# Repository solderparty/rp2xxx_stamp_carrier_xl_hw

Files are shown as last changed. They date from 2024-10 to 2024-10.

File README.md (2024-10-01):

# The RP2xxx Stamp Carrier Board XL

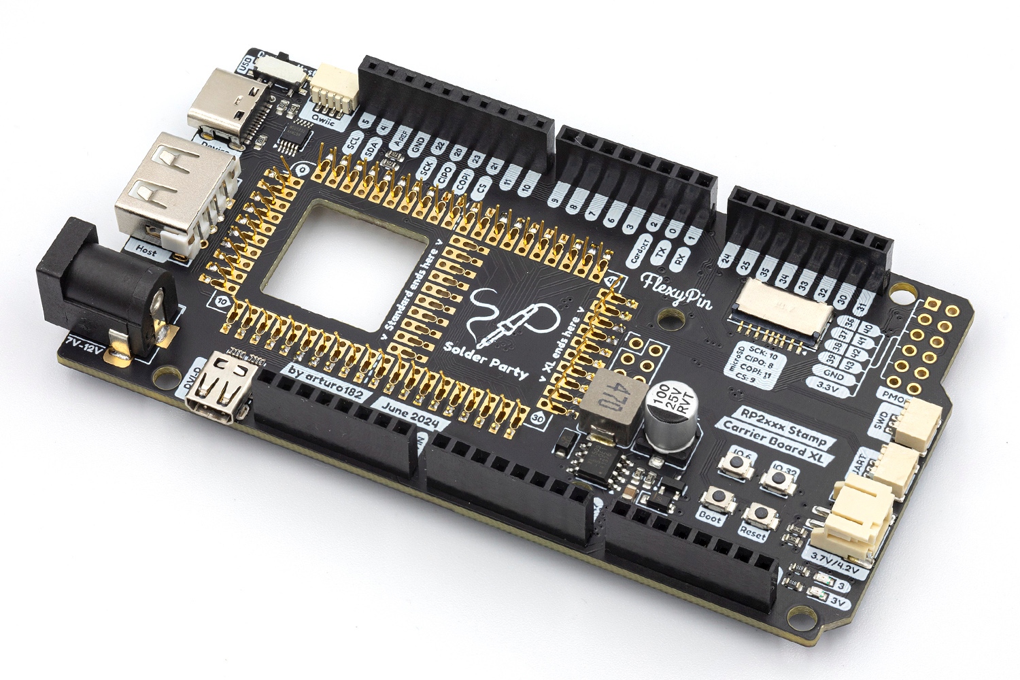
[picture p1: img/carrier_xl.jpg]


The RP2xxx Stamp Carrier XL, as the (somewhat long) name suggests, supports all the RP2-based Stamp boards. The Mega/Due form-factor ensures compatbility with many shields, including Uno ones. The wide range of connectors on the Carrier makes it a fully-fledged RP2xxx dev board.

The Carrier comes with a combo 3-in-1 SMD/TH/FlexyPin Stamp footprint, you can solder the Stamp directly to the Carrier, use 2mm pin headers + sockets to be able to plug it in and out, or use [FlexyPins](https://docs.solder.party/flexypin) to pop the Stamp in and out of the Carrier would soldering the Stamp. This way the Carrier also acts as a great Stamp flashing and testing jig. Check out the [Assembly Options](https://docs.solder.party/rp2xxx-stamp-carrier-xl/assembly_options) page for more details.

The board can be powered from the LiPo, over USB, or with a DC jack.

By using the RP2040 Stamp Carrier, you get everything that comes with the Stamp plus:

- USB Host and Device connectors with a toggle switch
- microSD socket
- Micro HDMI-shaped connector, connected to the HSTX peripheral
- SWD JST connector, compatible with the Raspberry Pi Pico Probe
- UART JST connector, compatible with the Raspberry Pi Pico Probe
- Qwiic connector
- 3.7/4.2V LiPo connector
- two user buttons
- PMOD header
- USR LED
- Power (3.3V) LED
- DC Jack

The DC Jack input is center-positive and supports voltages in the range of 7-12V. If you have the LiPo and either DC or USB connected, the battery will begin charging.

As mentioned above, the Carrier follows the Mega/Due/Uno shield pinout, making it compatible with a large ecosystem of shields, as long as they work on 3.3V IOs. **The pins are not 5V-tolerant**.

The CircuitPython firmware for the Stamps comes with a built-in board file for the Carrier, you can access it using `import stamp_carrier_board_xl as board`. After that, you can access all the Carrier pins and interfaces like you would with any other CPY board.

# Links

For more information visit https://rp2xxx-stamp-carrier-xl.solder.party/

Buy it on Lectronz (https://lectronz.com/products/rp2xxx-stamp-carrier-xl)

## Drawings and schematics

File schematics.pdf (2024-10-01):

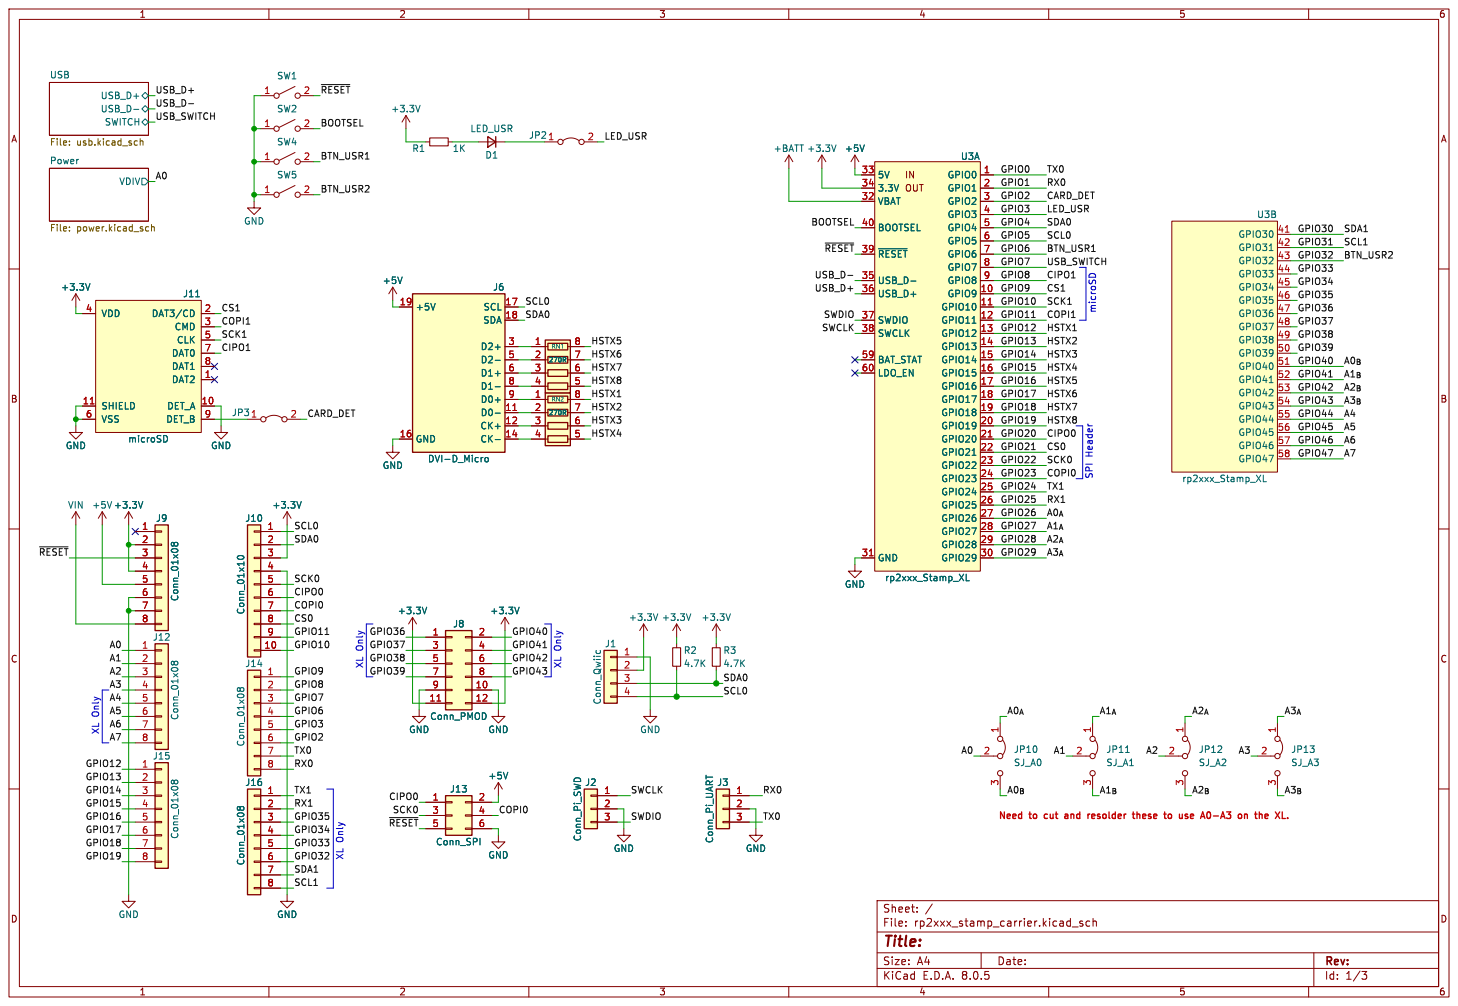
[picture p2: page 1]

Power File: power.kicad_sch USB_D+ USB_D- SWITCH

Id: 1/3 Title: File: rp2xxx_stamp_carrier.kicad_sch Sheet: /

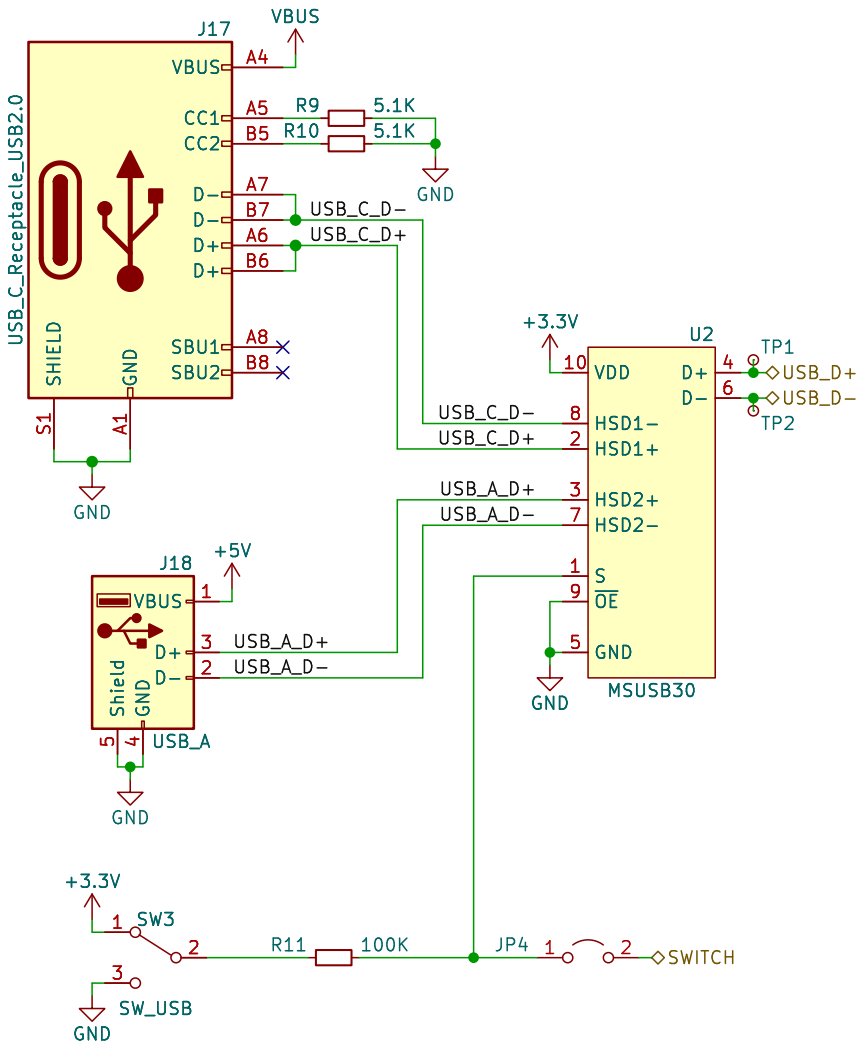
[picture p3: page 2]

Id: 2/3 Title: File: usb.kicad_sch Sheet: /USB/

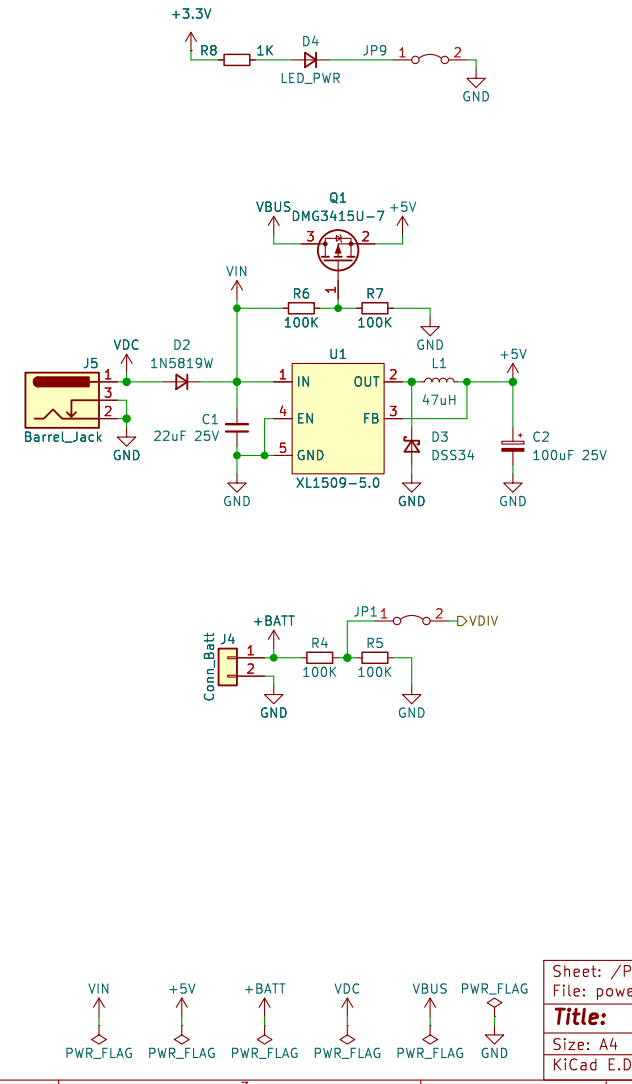
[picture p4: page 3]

Id: 3/3 Title: File: power.kicad_sch Sheet: /Power/ PWR_FLAG

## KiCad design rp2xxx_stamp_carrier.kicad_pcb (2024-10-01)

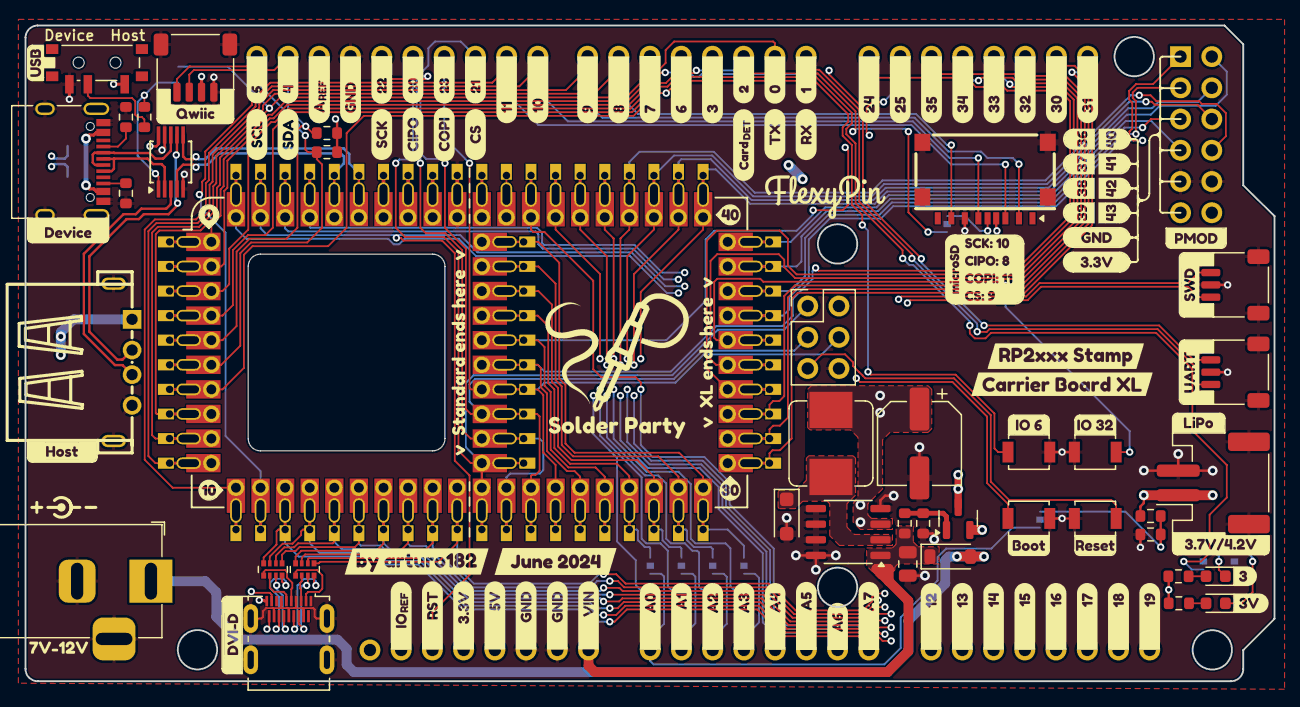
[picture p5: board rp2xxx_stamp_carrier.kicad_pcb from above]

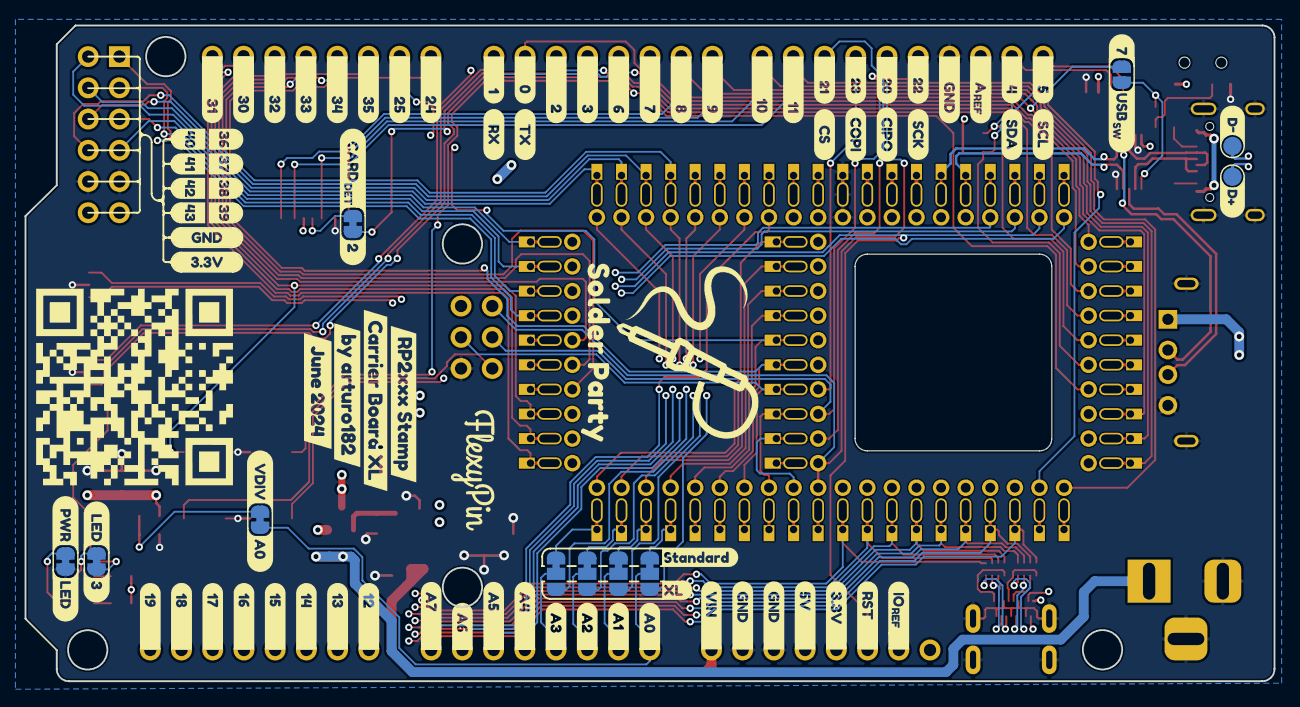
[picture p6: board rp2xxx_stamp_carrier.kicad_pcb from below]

Board: 4 copper layers, 101.6 x 53.3 mm, 255 parts (105 on the bottom side), 89 nets.

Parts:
C1: 22uF 25V; C_0805_2012Metric
C2: 100uF 25V; CP_Elec_6.3x4.9
D1: LED_USR; LED_0603_1608Metric
D2: 1N5819W; D_SOD-123
D3: DSS34; D_SOD-123F
D4: LED_PWR; LED_0603_1608Metric
J1: Conn_Qwiic; JST_SH_SM04B-SRSS-TB_1x04-1MP_P1.00mm_Horizontal
J2: Conn_Pi_SWD; JST_SH_SM03B-SRSS-TB_1x03-1MP_P1.00mm_Horizontal
J3: Conn_Pi_UART; JST_SH_SM03B-SRSS-TB_1x03-1MP_P1.00mm_Horizontal
J4: Conn_Batt; JST_PH_S2B-PH-SM4-TB_1x02-1MP_P2.00mm_Horizontal
J5: Barrel_Jack; BarrelJack_Horizontal
J6: DVI-D_Micro; HDMI_Micro-D_Molex_46765-1x01
J8: Conn_PMOD; PinSocket_2x06_P2.54mm_Vertical
J9, J12, J14, J15, J16: Conn_01x08; PinSocket_1x08_P2.54mm_Vertical
J10: Conn_01x10; PinSocket_1x10_P2.54mm_Vertical
J11: microSD; XUNPU_TF-123-ARP9Hxx
J13: Conn_SPI; PinHeader_2x03_P2.54mm_Vertical
J17: USB_C_Receptacle_USB2.0; USB_C_Receptacle_XKB_U262-16XN-4BVC11
J18: USB_A; USB_A_Receptacle_908-261A1011D10100
JP1: JP_VDIV; SolderJumper-2_P1.3mm_Bridged_RoundedPad1.0x1.5mm
JP2: JP_LED_USR; SolderJumper-2_P1.3mm_Bridged_RoundedPad1.0x1.5mm
JP3: JP_SD_DET; SolderJumper-2_P1.3mm_Bridged_RoundedPad1.0x1.5mm
JP4: JP_USB_SWITCH; SolderJumper-2_P1.3mm_Open_RoundedPad1.0x1.5mm
JP9: JP_LED_PWR; SolderJumper-2_P1.3mm_Bridged_RoundedPad1.0x1.5mm
JP10: SJ_A0; SolderJumper-3_P1.3mm_Bridged12_RoundedPad1.0x1.5mm
JP11: SJ_A1; SolderJumper-3_P1.3mm_Bridged12_RoundedPad1.0x1.5mm
JP12: SJ_A2; SolderJumper-3_P1.3mm_Bridged12_RoundedPad1.0x1.5mm
JP13: SJ_A3; SolderJumper-3_P1.3mm_Bridged12_RoundedPad1.0x1.5mm
L1: 47uH; L_Bourns_SRP7028A_7.3x6.6mm
Q1: DMG3415U-7; SOT-23
R1, R8: 1K; R_0603_1608Metric
R2, R3: 4.7K; R_0603_1608Metric
R4, R5, R6, R7, R11: 100K; R_0603_1608Metric
R9, R10: 5.1K; R_0603_1608Metric
RN1, RN2: 270R; R_Array_Convex_4x0402
SW1: BTN_RESET; SW_SPST_B3U-1000P
SW2: BTN_BOOTSEL; SW_SPST_B3U-1000P
SW3: SW_USB; SW_SPDT_PCM12
SW4: BTN_USR1; SW_SPST_B3U-1000P
SW5: BTN_USR2; SW_SPST_B3U-1000P
TP1: TP_USB_D+; TestPoint_Pad_D1.5mm
TP2: TP_USB_D-; TestPoint_Pad_D1.5mm
U1: XL1509-5.0; SOP-8_3.9x4.9mm_P1.27mm
U2: MSUSB30; MSOP-10_3x3mm_P0.5mm
U3: rp2xxx_Stamp_XL; RP2xx_Stamp_FlexyPin
kibuzzard-65DA3D92, kibuzzard-65DA3D92#2: G***; kibuzzard-65DA3D92
kibuzzard-65DA3D96, kibuzzard-65DA3D96#2: G***; kibuzzard-65DA3D96
kibuzzard-65DA3DCF: G***; kibuzzard-65DA3DCF
kibuzzard-65DA3ED0: G***; kibuzzard-65DA3ED0
kibuzzard-65DA3EE8, kibuzzard-65DA3EE8#2, kibuzzard-65DA3EE8#3, kibuzzard-65DA3EE8#4: G***; kibuzzard-65DA3EE8
kibuzzard-65DA13F9: G***; kibuzzard-65DA13F9
kibuzzard-65DA35ED: G***; kibuzzard-65DA35ED
kibuzzard-65DA43E4: G***; kibuzzard-65DA43E4
kibuzzard-65DA140C: G***; kibuzzard-65DA140C
kibuzzard-65DA141A: G***; kibuzzard-65DA141A
kibuzzard-65DA141E: G***; kibuzzard-65DA141E
kibuzzard-65DA143D: G***; kibuzzard-65DA143D
kibuzzard-65DA144D: G***; kibuzzard-65DA144D
kibuzzard-65DA145C: G***; kibuzzard-65DA145C
kibuzzard-65DA146D: G***; kibuzzard-65DA146D
kibuzzard-65DA148C: G***; kibuzzard-65DA148C
kibuzzard-65DA150C: G***; kibuzzard-65DA150C
kibuzzard-65DA150E: G***; kibuzzard-65DA150E
kibuzzard-65DA445F, kibuzzard-65DA445F#2: G***; kibuzzard-65DA445F
kibuzzard-65DA451B: G***; kibuzzard-65DA451B
kibuzzard-65DA451F: G***; kibuzzard-65DA451F
kibuzzard-65DA1408: G***; kibuzzard-65DA1408
kibuzzard-65DA1410: G***; kibuzzard-65DA1410
kibuzzard-65DA1413: G***; kibuzzard-65DA1413
kibuzzard-65DA1417: G***; kibuzzard-65DA1417
kibuzzard-65DA1440: G***; kibuzzard-65DA1440
kibuzzard-65DA1442: G***; kibuzzard-65DA1442
kibuzzard-65DA1448: G***; kibuzzard-65DA1448
kibuzzard-65DA1450: G***; kibuzzard-65DA1450
kibuzzard-65DA1453: G***; kibuzzard-65DA1453
kibuzzard-65DA1457: G***; kibuzzard-65DA1457
kibuzzard-65DA1460: G***; kibuzzard-65DA1460
kibuzzard-65DA1463: G***; kibuzzard-65DA1463
kibuzzard-65DA1466: G***; kibuzzard-65DA1466
kibuzzard-65DA1469: G***; kibuzzard-65DA1469
kibuzzard-65DA1470: G***; kibuzzard-65DA1470
kibuzzard-65DA1473: G***; kibuzzard-65DA1473
kibuzzard-65DA1483: G***; kibuzzard-65DA1483
kibuzzard-65DA1486: G***; kibuzzard-65DA1486
kibuzzard-65DA1492: G***; kibuzzard-65DA1492
kibuzzard-65DA1508: G***; kibuzzard-65DA1508
kibuzzard-65DA1511: G***; kibuzzard-65DA1511
kibuzzard-65DA1514: G***; kibuzzard-65DA1514
kibuzzard-65DA1517: G***; kibuzzard-65DA1517
kibuzzard-65DA4352: G***; kibuzzard-65DA4352
kibuzzard-65DA4391, kibuzzard-65DA4391#2, kibuzzard-65DA4391#3, kibuzzard-65DA4391#4: G***; kibuzzard-65DA4391
kibuzzard-65DA4455, kibuzzard-65DA4455#2: G***; kibuzzard-65DA4455
kibuzzard-65DA4463, kibuzzard-65DA4463#2: G***; kibuzzard-65DA4463
kibuzzard-65DA4468, kibuzzard-65DA4468#2: G***; kibuzzard-65DA4468
kibuzzard-65DA4513, kibuzzard-65DA4513#2: G***; kibuzzard-65DA4513
kibuzzard-65DA4517, kibuzzard-65DA4517#2: G***; kibuzzard-65DA4517
kibuzzard-65DB6F6F: G***; kibuzzard-65DB6F6F
kibuzzard-65DB8C3D: G***; kibuzzard-65DB8C3D
kibuzzard-65DB8C4A: G***; kibuzzard-65DB8C4A
kibuzzard-65DB8C5D: G***; kibuzzard-65DB8C5D
kibuzzard-65DB8C6C: G***; kibuzzard-65DB8C6C
kibuzzard-65DB8C35: G***; kibuzzard-65DB8C35
kibuzzard-65DB8C43: G***; kibuzzard-65DB8C43
kibuzzard-65DB8C55: G***; kibuzzard-65DB8C55
kibuzzard-65DB8C65: G***; kibuzzard-65DB8C65
kibuzzard-65DB8CB7: G***; kibuzzard-65DB8CB7
kibuzzard-65DB8EB0: G***; kibuzzard-65DB8EB0
kibuzzard-65DB9A5B: G***; kibuzzard-65DB9A5B
kibuzzard-65DB9AC9: G***; kibuzzard-65DB9AC9
kibuzzard-65DB9ADE: G***; kibuzzard-65DB9ADE
kibuzzard-65DB9BDD: G***; kibuzzard-65DB9BDD
kibuzzard-65DB9C6E: G***; kibuzzard-65DB9C6E
kibuzzard-65DB9FCE: G***; kibuzzard-65DB9FCE
kibuzzard-65DB9FED: G***; kibuzzard-65DB9FED
kibuzzard-65DB88A1: G***; kibuzzard-65DB88A1
kibuzzard-65DB90A8: G***; kibuzzard-65DB90A8
kibuzzard-65DB90AF: G***; kibuzzard-65DB90AF
kibuzzard-65DB90B6: G***; kibuzzard-65DB90B6
kibuzzard-65DB90CA: G***; kibuzzard-65DB90CA
kibuzzard-65DB92A0: G***; kibuzzard-65DB92A0
kibuzzard-65DB92A7: G***; kibuzzard-65DB92A7
kibuzzard-65DB92AF: G***; kibuzzard-65DB92AF
kibuzzard-65DB92BE: G***; kibuzzard-65DB92BE
kibuzzard-65DB92C6: G***; kibuzzard-65DB92C6
kibuzzard-65DB92CE: G***; kibuzzard-65DB92CE
kibuzzard-65DB92F8: G***; kibuzzard-65DB92F8
kibuzzard-65DB97A1: G***; kibuzzard-65DB97A1
kibuzzard-65DB97F6: G***; kibuzzard-65DB97F6
kibuzzard-65DB876F: G***; kibuzzard-65DB876F
kibuzzard-65DB884E: G***; kibuzzard-65DB884E
kibuzzard-65DB908D: G***; kibuzzard-65DB908D
kibuzzard-65DB909F: G***; kibuzzard-65DB909F
kibuzzard-65DB928A: G***; kibuzzard-65DB928A
kibuzzard-65DB931B: G***; kibuzzard-65DB931B
kibuzzard-65DB932B: G***; kibuzzard-65DB932B
kibuzzard-65DB8732: G***; kibuzzard-65DB8732
kibuzzard-65DB8845: G***; kibuzzard-65DB8845
kibuzzard-65DB8856: G***; kibuzzard-65DB8856
kibuzzard-65DB8860: G***; kibuzzard-65DB8860
kibuzzard-65DB9086: G***; kibuzzard-65DB9086
kibuzzard-65DB9096: G***; kibuzzard-65DB9096
kibuzzard-65DB9291: G***; kibuzzard-65DB9291
kibuzzard-65DB9299: G***; kibuzzard-65DB9299
kibuzzard-65DB9324: G***; kibuzzard-65DB9324
kibuzzard-65DBA05E: G***; kibuzzard-65DBA05E
kibuzzard-65DBA5ED: G***; kibuzzard-65DBA5ED
kibuzzard-65DBA047: G***; kibuzzard-65DBA047
kibuzzard-65DBA204: G***; kibuzzard-65DBA204
kibuzzard-65DBAB3B: G***; kibuzzard-65DBAB3B
kibuzzard-65DBAB4B: G***; kibuzzard-65DBAB4B
kibuzzard-65DBAB8B: G***; kibuzzard-65DBAB8B
kibuzzard-65DBAE3B: G***; kibuzzard-65DBAE3B
kibuzzard-65DBAE3E: G***; kibuzzard-65DBAE3E
kibuzzard-65DBAE42: G***; kibuzzard-65DBAE42
kibuzzard-65DBAE46: G***; kibuzzard-65DBAE46
kibuzzard-65DBAFC4: G***; kibuzzard-65DBAFC4
kibuzzard-65DBB0B8: G***; kibuzzard-65DBB0B8
kibuzzard-65DBB1B5: G***; kibuzzard-65DBB1B5
kibuzzard-65DBB3A0: G***; kibuzzard-65DBB3A0
kibuzzard-65DBB5CC: G***; kibuzzard-65DBB5CC
kibuzzard-65DBB07F: G***; kibuzzard-65DBB07F
kibuzzard-65DBB7FE: G***; kibuzzard-65DBB7FE
kibuzzard-65DBB28B: G***; kibuzzard-65DBB28B
kibuzzard-65DBB461: G***; kibuzzard-65DBB461
kibuzzard-65DBB727: G***; kibuzzard-65DBB727
kibuzzard-65DBBE17, kibuzzard-65DBBE17#2: G***; kibuzzard-65DBBE17
kibuzzard-65DBBE25, kibuzzard-65DBBE25#2: G***; kibuzzard-65DBBE25
kibuzzard-65DBBE65, kibuzzard-65DBBE65#2: G***; kibuzzard-65DBBE65
kibuzzard-65DBC04C: G***; kibuzzard-65DBC04C
kibuzzard-65DBC042: G***; kibuzzard-65DBC042
kibuzzard-65DBC046: G***; kibuzzard-65DBC046
kibuzzard-65DBC049: G***; kibuzzard-65DBC049
kibuzzard-65DBC50C: G***; kibuzzard-65DBC50C
kibuzzard-65DBC86E: G***; kibuzzard-65DBC86E
kibuzzard-65DBC416: G***; kibuzzard-65DBC416
kibuzzard-65DBC874: G***; kibuzzard-65DBC874
kibuzzard-65DBD3AD: G***; kibuzzard-65DBD3AD
kibuzzard-65DBD7D2, kibuzzard-65DBD7D2#2: G***; kibuzzard-65DBD7D2
kibuzzard-65DBD8C5, kibuzzard-65DBD8C5#2: G***; kibuzzard-65DBD8C5
kibuzzard-65DBD8CA, kibuzzard-65DBD8CA#2: G***; kibuzzard-65DBD8CA
kibuzzard-65DBD83D, kibuzzard-65DBD83D#2: G***; kibuzzard-65DBD83D
kibuzzard-65DBD87F, kibuzzard-65DBD87F#2: G***; kibuzzard-65DBD87F
kibuzzard-65DBD479: G***; kibuzzard-65DBD479
kibuzzard-65DBD837, kibuzzard-65DBD837#2: G***; kibuzzard-65DBD837
kibuzzard-65DBD847, kibuzzard-65DBD847#2: G***; kibuzzard-65DBD847
kibuzzard-65DBD875, kibuzzard-65DBD875#2: G***; kibuzzard-65DBD875
kibuzzard-65DBDBD8: G***; kibuzzard-65DBDBD8
kibuzzard-65DBDBE3: G***; kibuzzard-65DBDBE3
kibuzzard-65DBDBF9: G***; kibuzzard-65DBDBF9
kibuzzard-65DBDC20: G***; kibuzzard-65DBDC20
kibuzzard-65DBDC23: G***; kibuzzard-65DBDC23
kibuzzard-668C75B1: G***; kibuzzard-668C75B1
kibuzzard-668C75C6: G***; kibuzzard-668C75C6
kibuzzard-668C75DA: G***; kibuzzard-668C75DA
kibuzzard-668C76A7: G***; kibuzzard-668C76A7
kibuzzard-668C88D6: G***; kibuzzard-668C88D6
kibuzzard-668C88F2: G***; kibuzzard-668C88F2
kibuzzard-668C89D9: G***; kibuzzard-668C89D9
kibuzzard-668C97F2: G***; kibuzzard-668C97F2
kibuzzard-668C7671: G***; kibuzzard-668C7671
kibuzzard-668C7736: G***; kibuzzard-668C7736
kibuzzard-668C7740: G***; kibuzzard-668C7740
kibuzzard-668C7764: G***; kibuzzard-668C7764
kibuzzard-668C8744: G***; kibuzzard-668C8744
kibuzzard-668C9122: G***; kibuzzard-668C9122
kibuzzard-668C9635: G***; kibuzzard-668C9635
kibuzzard-6695ACF2: G***; kibuzzard-6695ACF2
kibuzzard-6695AD18: G***; kibuzzard-6695AD18
kibuzzard-6695BF60: G***; kibuzzard-6695BF60
kibuzzard-6695BFEA: G***; kibuzzard-6695BFEA
kibuzzard-6695CF81: G***; kibuzzard-6695CF81
kibuzzard-6695CF95: G***; kibuzzard-6695CF95
kibuzzard-660639E8: G***; kibuzzard-660639E8
kibuzzard-660639F3: G***; kibuzzard-660639F3
kibuzzard-669714D3: G***; kibuzzard-669714D3
kibuzzard-66063958: G***; kibuzzard-66063958
kibuzzard-66063979: G***; kibuzzard-66063979
svg2mod: G***; svg2mod

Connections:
+3.3V: J1.2, J8.11, J8.12, J9.2, J9.4, J10.3, J11.4 (VDD), R1.1, R2.1, R3.1, R8.1, SW3.1 (A), U2.10 (VDD), U3.34 (3.3V)
+5V: C2.1, J6.19 (+5V), J9.5, J13.2, J18.1 (VBUS), L1.2, Q1.2 (S), U1.3 (FB), U3.33 (5V)
+BATT: J4.1, R4.1, U3.32 (VBAT)
/A0: J12.1, JP1.2 (B), JP10.2 (C)
/A0_{A}: JP10.1 (A), U3.27 (GPIO26)
/A0_{B}: J8.2, JP10.3 (B), U3.51 (GPIO40)
/A1: J12.2, JP11.2 (C)
/A1_{A}: JP11.1 (A), U3.28 (GPIO27)
/A1_{B}: J8.4, JP11.3 (B), U3.52 (GPIO41)
/A2: J12.3, JP12.2 (C)
/A2_{A}: JP12.1 (A), U3.29 (GPIO28)
/A2_{B}: J8.6, JP12.3 (B), U3.53 (GPIO42)
/A3: J12.4, JP13.2 (C)
/A3_{A}: JP13.1 (A), U3.30 (GPIO29)
/A3_{B}: J8.8, JP13.3 (B), U3.54 (GPIO43)
/A4: J12.5, U3.55 (GPIO44)
/A5: J12.6, U3.56 (GPIO45)
/A6: J12.7, U3.57 (GPIO46)
/A7: J12.8, U3.58 (GPIO47)
/BOOTSEL: SW2.2 (B), U3.40 (BOOTSEL)
/BTN_USR1: J14.4, SW4.2 (B), U3.7 (GPIO6)
/BTN_USR2: J16.6, SW5.2 (B), U3.43 (GPIO32)
/CARD_DET: J14.6, JP3.2 (B), U3.3 (GPIO2)
/CIPO0: J10.6, J13.1, U3.21 (GPIO20)
/CIPO1: J11.7 (DAT0), J14.2, U3.9 (GPIO8)
/COPI0: J10.7, J13.4, U3.24 (GPIO23)
/COPI1: J10.9, J11.3 (CMD), U3.12 (GPIO11)
/CS0: J10.8, U3.22 (GPIO21)
/CS1: J11.2 (DAT3/CD), J14.1, U3.10 (GPIO9)
/GPIO0: J3.3, J14.7, U3.1 (GPIO0)
/GPIO1: J3.1, J14.8, U3.2 (GPIO1)
/GPIO3: J14.5, JP2.2 (B), U3.4 (GPIO3)
/GPIO4: J1.3, J6.18 (SDA), J10.2, R3.2, U3.5 (GPIO4)
/GPIO5: J1.4, J6.17 (SCL), J10.1, R2.2, U3.6 (GPIO5)
/GPIO7: J14.3, JP4.2 (B), U3.8 (GPIO7)
/GPIO10: J10.10, J11.5 (CLK), U3.11 (GPIO10)
/GPIO12: J15.1, RN2.8 (R1.2), U3.13 (GPIO12)
/GPIO13: J15.2, RN2.7 (R2.2), U3.14 (GPIO13)
/GPIO14: J15.3, RN2.6 (R3.2), U3.15 (GPIO14)
/GPIO15: J15.4, RN2.5 (R4.2), U3.16 (GPIO15)
/GPIO16: J15.5, RN1.8 (R1.2), U3.17 (GPIO16)
/GPIO17: J15.6, RN1.7 (R2.2), U3.18 (GPIO17)
/GPIO18: J15.7, RN1.6 (R3.2), U3.19 (GPIO18)
/GPIO19: J15.8, RN1.5 (R4.2), U3.20 (GPIO19)
/GPIO22: J10.5, J13.3, U3.23 (GPIO22)
/GPIO24: J16.1, U3.25 (GPIO24)
/GPIO25: J16.2, U3.26 (GPIO25)
/GPIO30: J16.7, U3.41 (GPIO30)
/GPIO31: J16.8, U3.42 (GPIO31)
/GPIO33: J16.5, U3.44 (GPIO33)
/GPIO34: J16.4, U3.45 (GPIO34)
/GPIO35: J16.3, U3.46 (GPIO35)
/GPIO36: J8.1, U3.47 (GPIO36)
/GPIO37: J8.3, U3.48 (GPIO37)
/GPIO38: J8.5, U3.49 (GPIO38)
/GPIO39: J8.7, U3.50 (GPIO39)
/SWCLK: J2.1, U3.38 (SWCLK)
/SWDIO: J2.3, U3.37 (SWDIO)
/USB/USB_A_D+: J18.3 (D+), U2.3 (HSD2+)
/USB/USB_A_D-: J18.2 (D-), U2.7 (HSD2-)
/USB/USB_C_D+: J17.A6 (D+), J17.B6 (D+), U2.2 (HSD1+)
/USB/USB_C_D-: J17.A7 (D-), J17.B7 (D-), U2.8 (HSD1-)
/USB_D+: TP1.1, U2.4 (D+), U3.36 (USB_D+)
/USB_D-: TP2.1, U2.6 (D-), U3.35 (USB_D-)
/~RESET: J9.3, J13.5, SW1.2 (B), U3.39 (~RESET)
GND: C1.1, C2.2, D3.2 (A), J1.1, J2.2, J3.2, J4.2, J5.2, J5.3, J6.4 (D2S), J6.7 (D1S), J6.10 (D0S), J6.13 (CKS), J6.16 (GND), J6.SH, J8.9, J8.10, J9.6, J9.7, J10.4, J11.6 (VSS), J11.11 (SHIELD), J13.6, J17.A1 (GND), J17.A12 (GND), J17.B1 (GND), J17.B12 (GND), J17.S1 (SHIELD), J18.4 (GND), J18.5 (Shield), JP9.2 (B), R5.2, R7.2, R9.2, R10.2, SW1.1 (A), SW2.1 (A), SW3.3 (C), SW4.1 (A), SW5.1 (A), U1.4 (EN), U1.5 (GND), U1.6 (GND), U1.7 (GND), U1.8 (GND), U2.5 (GND), U2.9 (~OE), U3.31 (GND)
unnamed: D1.2 (A), R1.2
unnamed: D1.1 (K), JP2.1 (A)
unnamed: D3.1 (K), L1.1, U1.2 (OUT)
unnamed: D4.2 (A), R8.2
unnamed: D4.1 (K), JP9.1 (A)
unnamed: J6.12 (CK+), RN2.3 (R3.1)
unnamed: J6.14 (CK-), RN2.4 (R4.1)
unnamed: J6.9 (D0+), RN2.1 (R1.1)
unnamed: J6.11 (D0-), RN2.2 (R2.1)
unnamed: J6.6 (D1+), RN1.3 (R3.1)
unnamed: J6.8 (D1-), RN1.4 (R4.1)
unnamed: J6.3 (D2+), RN1.1 (R1.1)
unnamed: J6.5 (D2-), RN1.2 (R2.1)
unnamed: J11.9 (DET_B), JP3.1 (A)
unnamed: J17.A5 (CC1), R9.1
unnamed: J17.B5 (CC2), R10.1
unnamed: JP1.1 (A), R4.2, R5.1
unnamed: JP4.1 (A), R11.2, U2.1 (S)
unnamed: Q1.1 (G), R6.2, R7.1
unnamed: R11.1, SW3.2 (B)
VBUS: J17.A4 (VBUS), J17.A9 (VBUS), J17.B4 (VBUS), J17.B9 (VBUS), Q1.3 (D)
VDC: D2.2 (A), J5.1
VIN: C1.2, D2.1 (K), J9.8, R6.1, U1.1 (IN)

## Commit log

2023-12-13 Rev 0
    [rp2350_stamp_carrier.kicad_pcb, rp2350_stamp_carrier.kicad_sch, usb.kicad_sch]
2024-02-26 Rev 1
    [power.kicad_sch, rp2350_stamp_carrier.kicad_pcb, rp2350_stamp_carrier.kicad_sch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]
2024-03-29 Rev 2
    Fixed HDMI connector
    Swapped RST and BOOTSEL buttons to match Stamp
    Added BAT_STAT to Stamp
    Changed 2x silk back to single line
    Adjusted Name silkscreen
    [rp2xxx_stamp_carrier.kicad_pcb, rp2xxx_stamp_carrier.kicad_sch]
2024-07-16 Rev 3
    - USB Switch jumper open by default
    - Power USB Host from 5V not VBUS
    - Fix SPI pin silkscreen
    - Add test points for USB D+/D-
    [power.kicad_sch, rp2xxx_stamp_carrier.kicad_pcb, rp2xxx_stamp_carrier.kicad_sch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]
2024-10-01 Rev 3.1, add README, and LICENSE
    - Fixed the microSD pin silkscreen
    - Updated BOM
    [power.kicad_sch, rp2xxx_stamp_carrier.kicad_pcb, rp2xxx_stamp_carrier.kicad_sch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]
